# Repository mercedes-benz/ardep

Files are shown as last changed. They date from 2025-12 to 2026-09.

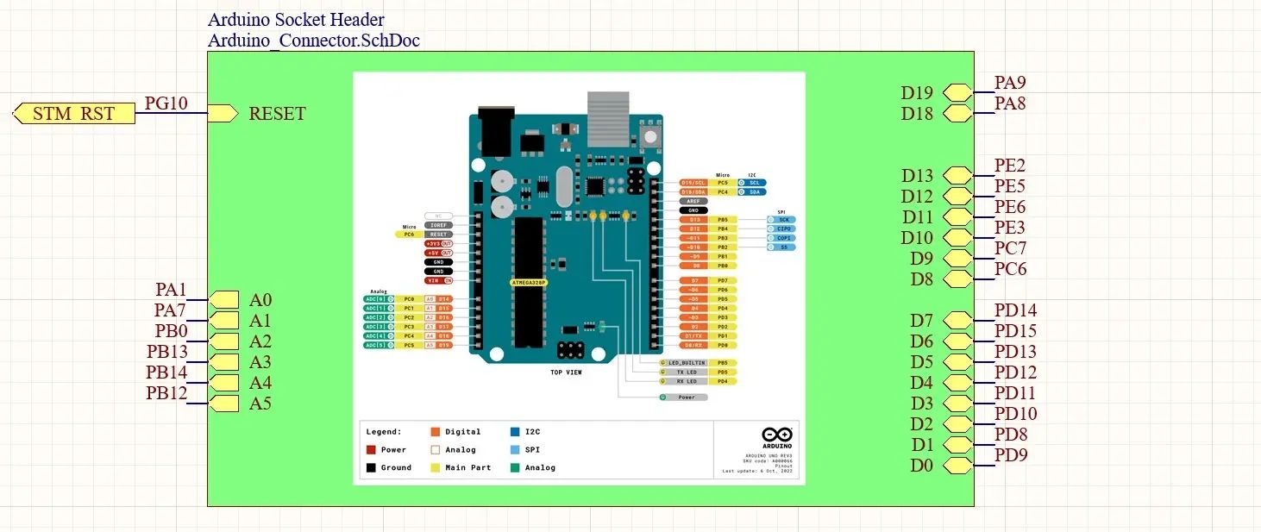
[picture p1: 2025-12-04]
_images/arduino_pinout_rev0_1.jpg

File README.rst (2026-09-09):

ARDEP - Automotive Rapid Development Platform
#############################################



ARDEP (**A**\ utomotive **R**\ apid **DE**\ velopment **P**\ latform) is an open-source hardware and software platform 
that simplifies automotive development. It combines a feature-rich development board with a robust 
Zephyr-based software framework, enabling you to build and deploy automotive applications quickly.

Whether you're prototyping a new automotive device or experimenting with diagnostics,
ARDEP provides the tools and infrastructure you need.

Waypoints
=========

* **Documentation**
   * `Documentation <https://mercedes-benz.github.io/ardep/>`_
   * `Getting Started Guide <https://mercedes-benz.github.io/ardep/getting_started/index.html>`_

* **Hardware**
   * `Hardware documentation <https://mercedes-benz.github.io/ardep/boards/mercedes/ardep/doc/index.html>`_
   * `PowerIO Shield documentation <https://mercedes-benz.github.io/ardep/boards/shields/power_io_shield/doc/index.html>`_
   * `Hardware files <hardware/>`_
   * `Get the hardware (Crowd Supply) <https://www.crowdsupply.com/frickly-systems/ardep>`_

* **Software**
   * `UDS Library documentation <https://mercedes-benz.github.io/ardep/lib/uds/README.html>`_
   * `Sample documentation <https://mercedes-benz.github.io/ardep/samples/>`_
   * `Sample sources <samples/>`_

* **Project**
   * `Contributing guidelines <CONTRIBUTING.md>`_
   * `License <LICENSE>`_

At a Glance
===========

* **Complete hardware solution** - Ready-to-use development board with CAN, LIN and other common communication interfaces
* **PowerIO Shield** - Extended Power capabilities for 6 Outputs and 6 Inputs up to 48V and 3A per channel
* **Automotive-ready software** - Built-in UDS diagnostics (ISO 14229) and DFU firmware update support
* **Proven foundation** - Based on the reliable Zephyr RTOS with a large ecosystem
* **Fast prototyping** - Develop and iterate quickly without worrying about hardware integration

Key Features
============

**Hardware**

* **Integrated development board** - Open-source design with everything you need built-in
* **Automotive communication** - Onboard CAN and LIN transceivers (no external components needed)
* **Debugger & programmer onboard** - Integrated debugger and programmer with UART connection
* **PowerIO Shield** - Extended power capabilities with six 3A high-side switches at up to 48V
* **Arduino headers** - Compatible with a wide range of Arduino shields and accessories

**Software & Framework**

* **Zephyr RTOS based** - Built on the reliable, widely-adopted open-source Zephyr RTOS
* **Automotive diagnostics** - Built-in UDS support (ISO 14229) for professional diagnostics
* **Firmware updates** - Integrated DFU (Device Firmware Update) over UDS
* **Modular architecture** - Clean separation of concerns, designed for long-term maintainability
* **Rich connectivity** - CAN, LIN, SPI, I2C, UART and more with unified and easy-to-use APIs

Hardware availability
===============

Frickly Systems has started a Crowd Supply campaign to make the hardware available for purchase. Subscribe to notified when it launches at:



Getting Started
===============

Ready to dive in? Start with the `Getting Started Guide <https://mercedes-benz.github.io/ardep/getting_started/index.html>`_ 
for a comprehensive step-by-step introduction. You'll find sample projects and examples to help you get up and running quickly.

For detailed information on using ARDEP, API references, and troubleshooting, refer to the 
`complete documentation <https://mercedes-benz.github.io/ardep/>`_.

Contributing
============

Contributions are welcome and appreciated.
Please see `CONTRIBUTING.md <CONTRIBUTING.md>`_ for guidelines and further
information.

License
=======

Copyright Mercedes-Benz AG

This project is licensed under the `Apache 2.0 License <LICENSE>`_.

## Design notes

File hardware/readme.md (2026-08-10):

# Hardware Source files
This directory includes all hardware source files for the ARDEP Mainboard and auxilary shields.

## KiCad Conversion
The initial project development was started in Altium designer. After the Hardware release of the ARDEP Mainboard rev 2.1 and the Power IO shield rev 1.0 in December 2025, the Altium source files were converted to KiCad.

From this point on, the KiCad source files are considered as the active project documents while the Altium source files are treated as legacy data and will no longer be actively maintained.

## OpenSCAD file
OpenSCAD enclosure models are stored in this hardware folder as source .scad files.
Use descriptive names such as ardep_enclosure.scad and prefer parametric dimensions/cutouts.
For each new model, include a short note with parameters and recommended print settings.
Generated STL files should only be committed when explicitly requested by maintainers.

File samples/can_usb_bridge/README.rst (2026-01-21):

.. _can_usb_bridge_sample:

CAN USB Bridge sample
#####################

This sample uses the application from the CANnectivity repository and just provides overlays for compatability with the ARDEP board.

It creates a CAN to USB bridge connecting *CAN A* of the ARDEP board to the USB Host.

The `CANnectivity repository <https://github.com/CANnectivity/cannectivity>`_ is automatically downloaded as a Zephyr module with ``west update`` on workspace setup. You can find it under ``{WORKSPACE_ROOT}/modules/lib/cannectivity``.

As a *one-time setup*, you need to install the CANnectivity UDEV rule (analogous to the one we installed in :ref:`getting_started` guide):

.. code-block::

    sudo cp {WORKSPACE_ROOT}/modules/lib/cannectivity/99-cannectivity.rules /etc/udev/rules.d/
    sudo udevadm control --reload-rules
    sudo udevadm trigger

.. note::

    Since the app manages the usb stack, there will be no USB-CDC-ACM device present to see the logs.
    Instead, they are redirected to UART-A (The same UART the bootloader uses).

Flash and run the example
-------------------------

Build the example with:

.. tabs::

    .. tab:: Ardep v2.0.0 and later
        .. code-block::

            west build --board ardep@2.0.0 ../modules/lib/cannectivity/app -- \
                -DFILE_SUFFIX=usbd_next \
                -DEXTRA_CONF_FILE=../../../../ardep/samples/can_usb_bridge/cannectivity.conf \
                -DEXTRA_DTC_OVERLAY_FILE=../../../../ardep/samples/can_usb_bridge/cannectivity_2_0_0.overlay

    .. tab:: Ardep v1.0.0

        .. code-block::

            west build --board ardep@1.0.0 ../modules/lib/cannectivity/app -- \
                -DFILE_SUFFIX=usbd_next \
                -DEXTRA_CONF_FILE=../../../../ardep/samples/can_usb_bridge/cannectivity.conf \
                -DEXTRA_DTC_OVERLAY_FILE=../../../../ardep/samples/can_usb_bridge/cannectivity_1_0_0.overlay
                
The ``FILE_SUFFIX`` selects the `prj_usbd_next.conf` file from the CANnectivity app folder, which enables the new USB stack.

The ``EXTRA_CONF_FILE`` and ``EXTRA_DTC_OVERLAY_FILE`` options specify the additional configuration and overlay files found in the samples directory.
The path is relative to the application directory.

Flash the app using dfu-util:

.. code-block:: bash

    west flash

After flashing, you should see an USB device named "Generic CANnectivity USB to CAN adapter" with a VID/PID of ``1209:ca01``.
Additionally you should also see a new can device on your host system.
Configure it as follows to enable it:

.. code-block:: bash
   
    # Replace can0 with the device name on your system

    sudo ip link set can0 type can bitrate 500000
    sudo ip link set up can0

.. warning::
   
    For users of the *ARDEPv1* board:

    Since we don't use the default USB PID/VID of the ARDEP board, the default ARDEP DFU will not work for firmware updates.
    Put the device in bootloader mode to flash another firmware.

    See :ref:`bootloader_mode` for more information.

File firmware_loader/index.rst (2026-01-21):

.. _firmware_loader:

Firmware Loader
###############

This firmware loader is used to update **application** firmware on ARDEP devices. It supports both **UDS DFU** (Unified Diagnostic Services over CAN) and **USB DFU** (Device Firmware Update via USB), providing flexible firmware update mechanisms for all ARDEP board versions.

The bootloader runs this firmware under certain conditions, such as when the *BOOT* labeled jumper is set during start up,
when ``uds_switch_to_firmware_loader_with_programming_session()`` is called (or automatically with the UDS default instance), or when no valid application is flashed.

The firmware loader uses the UDS library's default instance for simplified UDS server setup, automatically handling CAN configuration and session management. It also provides USB DFU functionality for USB-based firmware updates.

.. important::

    Only applications can be updated via the firmware loader. Not the bootloader or the firmware loader itself.

For this firmware loader to work as intended, use sysbuild to build the bootloader with this firmware loader.

.. note::
    **Default for all boards**: This unified firmware loader is now the default boot logic for all ARDEP board versions (v1 and v2), eliminating the previous distinction between boards. Both UDS DFU and USB DFU are supported on all boards for application updates.
    
    **Upgrading from older ARDEP versions**: If you're using an older ARDEP repository version that differentiated between board versions, you must upgrade your bootloader via sysbuild using a debugger (OBD or external probe) to install the unified firmware loader.

Usage
+++++

The firmware loader supports two update mechanisms:

**UDS DFU (CAN-based updates):**

This firmware registers an *erase slot0* routine with id ``0xFF00`` which, if started via UDS, erases slot0 (the application slot).

Then, using `RequestDownload`, `TransferData`, `RequestTransferExit` the application can be updated. Finally, use an `ECUReset` to let mcuboot boot into the fresh application.

**USB DFU (USB-based updates):**

When the firmware loader is active and the device is connected via USB, it can accept firmware updates using the standard ``dfu-util`` tool.

- **v1 boards**: The default ``west flash`` runner uses dfu-util, so simply set the BOOT jumper, reset the board, and run ``west flash``
- **v2 boards**: To use USB DFU instead of the OBD run ``west flash --runner ardep``. Note that is usually better to use the on-board debugger (OBD) for flashing v2 boards.

Flashing firmware
+++++++++++++++++

If your application supports UDS firmware loading, you can use the :ref:`ardep_uds` runner to flash the new firmware.

Building using sysbuild
+++++++++++++++++++++++

See :ref:`uds_bootloader` on building an application together with this firmware loader.

The firmware loader is automatically included when building with sysbuild and provides both UDS and USB DFU support by default.

A good starting point in using this loader is using the :ref:`uds-sample`.

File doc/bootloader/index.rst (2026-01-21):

.. _bootloader:
   
Bootloader
##########

.. contents::
   :local:
   :depth: 2

Overview
++++++++

The ARDEP bootloader uses MCUBoot and a :ref:`firmware_loader` for firmware updates. This enables application upgrades either via UDS over CAN or USB DFU.

.. tabs::

    .. tab:: Ardep v2.0.0 and later

        The recommended upgrade mechanism is the on-board debugger using the `west flash` command or if needed using UDS over CAN.

    .. tab:: Ardep v1.0.0

        The recommended upgrade mechanism is USB DFU using the `west flash` command or if needed using UDS over CAN.

Building the bootloader
+++++++++++++++++++++++

The bootloader can be built using sysbuild together with a sample for flashing. To reset the board to a delivery state, use 

.. code-block:: bash

    west build -b ardep samples/led -p --sysbuild

to build the :ref:`led_sample` and bootloader

If you want to build for a specific board version, change the `-b` argument accordingly:

.. code-block:: bash

    west build -b ardep@1.0.0 samples/led -p --sysbuild

.. _flashing_the_bootloader:

Flashing the bootloader
+++++++++++++++++++++++

.. important::

    **Bootloader and firmware loader can ONLY be flashed via debugger:**
    
    - **v2.0.0 and later**: Must use the on-board debugger (OBD) - this is the **recommended and default** method
    - **v1.0.0**: Must use an external debug probe (e.g. J-Link, ST-Link)
    
    The firmware loader itself **cannot** be flashed via USB DFU or UDS DFU. Only **application** updates can use the firmware loader's DFU capabilities.

.. tabs::

    .. tab:: Ardep v2.0.0 and later

        The bootloader and firmware loader are flashed via the on-board debugger using the `west flash` command.

        Just run:

        .. code-block:: bash

            west flash

        This will flash the bootloader and firmware loader to the board.

    .. tab:: Ardep v1.0.0

        The bootloader and firmware loader are flashed with an external debug probe (e.g. J-Link) using the `west flash` command.

        For this connect the SWD Pins of the ARDEP board to the debug probe an run:

        .. code-block:: bash
           
            west flash -r {runner}

        The Pinout of the SWD connector is printed on the boards backside.

        See the `board.cmake` file under `boards/mercedes/ardep` for more info about supported debuggers/runners.

.. _bootloader_mode:

Firmware Loader Mode
++++++++++++++++++++

The firmware loader supports both **USB DFU** and **UDS DFU** update mechanisms for **application** updates. When you set the BOOT jumper, the bootloader enters the firmware loader, which provides both update methods.

.. important::

    The firmware loader can only update **applications**, not the bootloader or firmware loader itself. To update the bootloader or firmware loader, you must use the on-board debugger (v2) or external probe (v1).

It is helpful to see the Bootloader console output on ``UART-A`` for this.

Entering Firmware Loader Mode
==============================

To enter the firmware loader mode, pull the ``PE4`` pin (labeled *BOOT*) to a LOW state (by setting the jumper) while power-cycling or pushing the Reset button.

The firmware loader will be active and ready to accept **application** firmware updates via either USB DFU or UDS (CAN).

On ``UART-A`` you will see output indicating the bootloader has started the firmware loader.

.. note::

    ``UART-A`` is the output that is forwarded by the on-board debugger (on v2 boards) or available via the UART-A pins.

Upgrading the Application Firmware
===================================

You can upgrade **application** firmware using either method:

**Via On-board Debugger (v2)**

- Note that this method only works on ARDEP v2.0.0 and later boards with an on-board debugger.
- Build the application firmware you want to flash (assuming it is in the *build* directory)
- Set the BOOT jumper and reset the board
- Perform the upgrade with ``west flash``
- Wait for the upgrade to complete

**Via USB DFU:**

- Note that this method works on all ARDEP boards (v1 and v2), but the first option is generally better for v2+ boards
- Build the application firmware you want to flash (assuming it is in the *build* directory)
- Set the BOOT jumper and reset the board
- Perform the upgrade with ``west flash`` (for v2+ boards, set the runner: ``west flash --runner ardep``)
- Wait for the upgrade to complete

**Via UDS (CAN):**

- Use the UDS diagnostic services over CAN to request a programming session
- The firmware loader will handle the application update process
- See :ref:`firmware_loader` for details

.. _uds_bootloader:

UDS and USB DFU Support via Firmware Loader
++++++++++++++++++++++++++++++++++++++++++++

.. note::

    **All ARDEP boards** (v1 and v2): The unified firmware loader is now the **default** boot logic for all board versions. You can build any application with sysbuild and it will automatically include the firmware loader with support for both UDS DFU and USB DFU.
    
    **Upgrading from older ARDEP versions**: If your bootloader was built with an older ARDEP repository version that differentiated between board versions, you need to upgrade the bootloader using sysbuild (via OBD on v2 or external probe on v1) to get the unified firmware loader support.

For applications that require firmware updates over UDS (Unified Diagnostic Services) or USB DFU,
a :ref:`firmware_loader` is provided which can be built using sysbuild.

It is not recommended to build the firmware loader independently as the bootloader needs configuration options to handle the firmware loader correctly.

For demonstration purposes, build the :ref:`uds-sample` using sysbuild (which contains a ``sysbuild.conf``), which automatically builds the firmware loader:

.. code-block:: bash

    west build -b ardep samples/uds -p --sysbuild

If you wish to build your own application using the firmware loader, it is included by default when using sysbuild.

.. note::
    **Flashing considerations:**
    
    - **Bootloader and firmware loader**: Can ONLY be flashed via on-board debugger (v2) or external probe (v1)
    - **Applications**: Can be flashed via debugger OR via the firmware loader (USB DFU/UDS DFU)
    
    See :ref:`flashing_the_bootloader` for detailed instructions.

.. important::
    When using the default UDS instance (``CONFIG_UDS_DEFAULT_INSTANCE=y``, enabled by default on ARDEP boards), the firmware loader switch is handled automatically on programming session requests unless disabled with ``CONFIG_UDS_DEFAULT_INSTANCE_DISABLE_SWITCH_TO_FIRMWARE_LOADER=y``.
    
    If you create a custom UDS instance or disable the automatic switch, you must call ``uds_switch_to_firmware_loader_with_programming_session()`` in your diagnostic session control action handler when a programming session is requested.

To flash an application with the UDS firmware loader, see :ref:`ardep_uds`.

Sysbuild
++++++++

With sysbuild, multiple applications (i.e. bootloader, main application and firmware loader) are built together using just one build command.

More information is available in the official `Zephyr Sysbuild documentation <https://docs.zephyrproject.org/4.2.0/build/sysbuild/index.html>`_.

Sysbuild basics
===============

There are multiple things that differ from a normal west build:

First, there are multiple targets for using menuconfig, one for each "domain":

.. code-block:: bash

    # Main application menuconfig
    west build -t menuconfig

    # Bootloader menuconfig
    west build -t mcuboot_menuconfig

    # Firmware loader menuconfig
    west build -t firmware_loader_menuconfig

    # Sysbuild menuconfig
    west build -t sysbuild_menuconfig

Second, you can switch between domains when debugging by specifying the domain:

.. code-block:: bash

    # Debug main application
    west debug

    # Debug bootloader
    west debug --domain mcuboot

    # Debug firmware loader
    west debug --domain firmware_loader

Finally, when flashing, you can either specify no domain, which flashes all domains in series or you can specify a domain to flash only that domain:

.. code-block:: bash

    # Flash all domains (bootloader, firmware loader and main application)
    west flash

    # Flash only bootloader
    west flash --domain mcuboot

    # Flash only firmware loader
    west flash --domain firmware_loader

    # Flash only main application (when building sample/uds the sample-name would be uds)
    west flash --domain <sample-name>

.. important::
    Note that on ARDEP v1 boards, only the main application can be flashed using the ardep runner. This also means that the bootloader and firmware loader must be flashed using an external debug probe, see :ref:`flashing_the_bootloader`.

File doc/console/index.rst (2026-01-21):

.. _console:

Console Output
##############

.. contents::
   :local:
   :depth: 2

Firmware Output
===============

The application output is sent on ``UART-A``.

.. tabs::

    .. tab:: Ardep v2.0.0 and later

        The output of the application is additionally forwarded via the on-board debugger to a USB cdc-acm device on the host system.

    .. tab:: Ardep v1.0.0

       By default, every application built for the *ardep* board will include a USB cdc-acm driver.
       This means, when connecting the board via USB to your PC, a new serial device should be visible in your system.

You can use the cdc-acm device to communicate with the board. The default baudrate is 115200.

.. tabs::

    .. tab:: Linux
    
        The serial device is usually displayed as */dev/ttyACMx*, */dev/ttyUSBx* or similar.

        Use a serial terminal emulator (e.g. *screen*, *minicom*, *picocom*) to connect to the device.
        
        .. code-block:: bash

            screen /dev/ttyACM0 115200

    .. tab:: Windows

        The serial device is usually displayed in your *Windows Device Manager* under *Ports (COM & LPT)* e.g. as *COM5*.

        Use *putty* or a similar terminal emulator to connect to the device.

        Connect to the COM port by selecting *Serial* in the *Connection type* section and entering the COM port number (e.g. *COM5*) in the *Serial line* field, setting the speed to 115200.

Bootloader and Firmware Loader Output
======================================

The bootloader and firmware loader output is available on the ``UART-A`` interface.

.. tabs::

    .. tab:: Ardep v2.0.0 and later

       Just as the firmware's output, the bootloader and firmware loader output is also forwarded via the on-board debugger to a cdc-acm device on the host system.

    .. tab:: Ardep v1.0.0

       The bootloader and firmware loader do not contain the cdc-acm driver and only emit output via ``UART-A``.
       If you want to see the bootloader or firmware loader output on your PC, you will need an external UART to USB adapter connected to the ``UART-A`` pins.

.. note::
    
    The unified firmware loader is now used by default on all board versions, supporting both UDS DFU and USB DFU update mechanisms.

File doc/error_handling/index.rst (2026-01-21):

.. _error_handling:

Error Handling
##############

.. contents::
   :local:
   :depth: 2

.. note::

    The following instructions only apply to Ardep v1 since later versions have an :ref:`on_board_debugger` and the bootloader logs are accessible via the forwarded UART-A device.
    Additionally, you can flash the bootloader and the firmware via ``west flash`` using the on-board debugger.
    
    **All ARDEP boards** now use the unified firmware loader by default, which supports both USB DFU and UDS DFU for firmware updates.

When encountering an error, you have several options, depending on the severity of the error.
Generally, it is helpful to see if your application gets started from the bootloader.
See the :ref:`console` documentation for more information about where you find the application and bootloader output.

If your application keeps running, you can just perform an update via the firmware loader. See the :ref:`getting_started` guide for an example.
The unified firmware loader supports both USB DFU and UDS DFU update mechanisms.
    
If your application keeps hanging itself up (e.g. segfaults) and a firmware loader update is not possible, boot into the :ref:`bootloader_mode` and flash a new application from there.

If you can't get into bootloader mode, you should delete the whole flash memory and flash a new bootloader and application.
For this, you need to connect an external debugger on the SWD pins on the board (or use the on-board debugger on v2 boards).

To build the bootloader with the unified firmware loader, you can use sysbuild:

    ``west build -b ardep samples/led -p --sysbuild``
    
Then erase the flash memory of the ardep board.

Next, flash the bootloader. You can use a debugger of your choice or use the ``west flash`` command.
For an overview of the ``west flash`` command see `Zephyr's documentation on the west command <https://docs.zephyrproject.org/4.2.0/develop/west/build-flash-debug.html#flashing-west-flash>`_, ``west flash -h`` and the *board.cmake* file under *boards/mercedes/ardep* for an overview of supported runners.

**Important**: The bootloader and firmware loader can ONLY be flashed via on-board debugger (v2) or external debug probe (v1).

After flashing the bootloader, flash the application of your choice. See the :ref:`getting_started` guide and the :ref:`bootloader_mode` documentation for this.

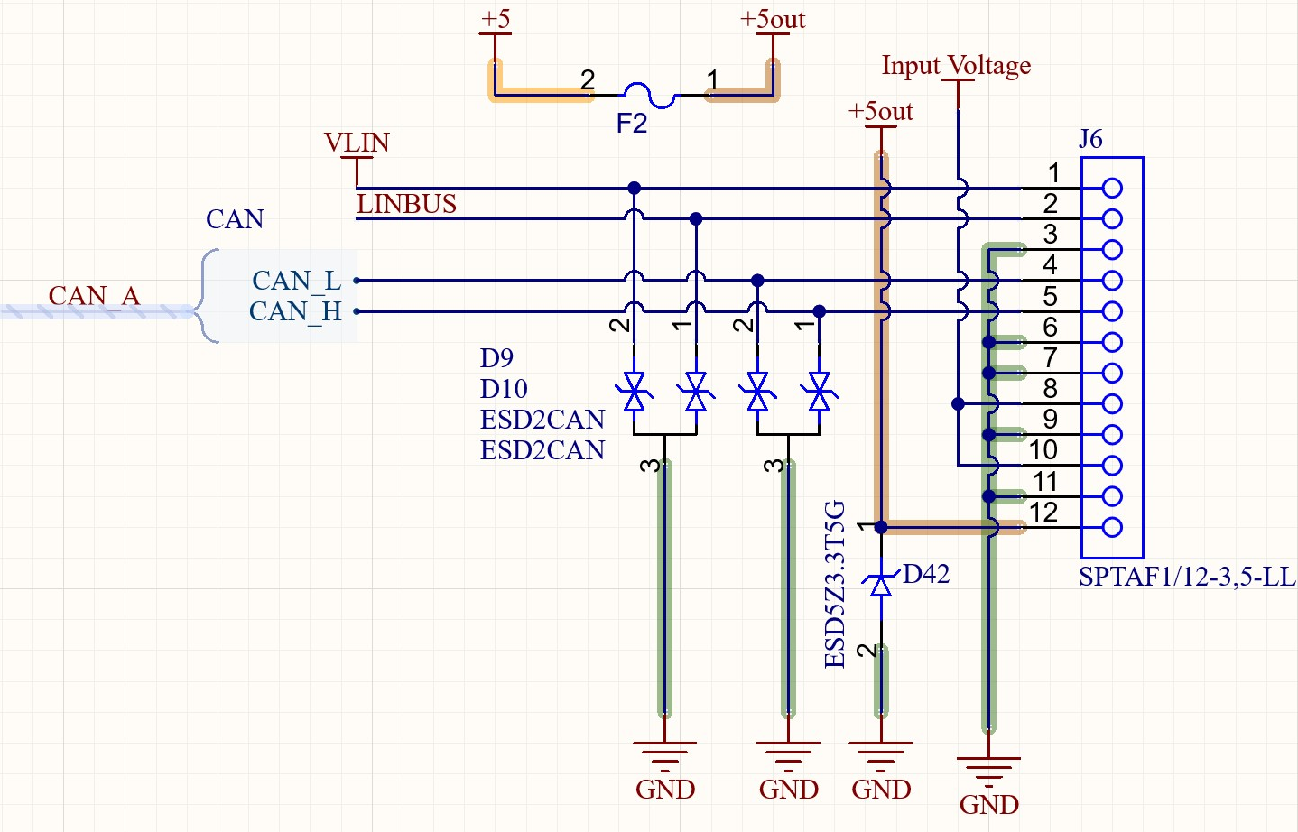
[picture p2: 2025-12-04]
_images/can_and_lin_spring_terminal_pinout.png

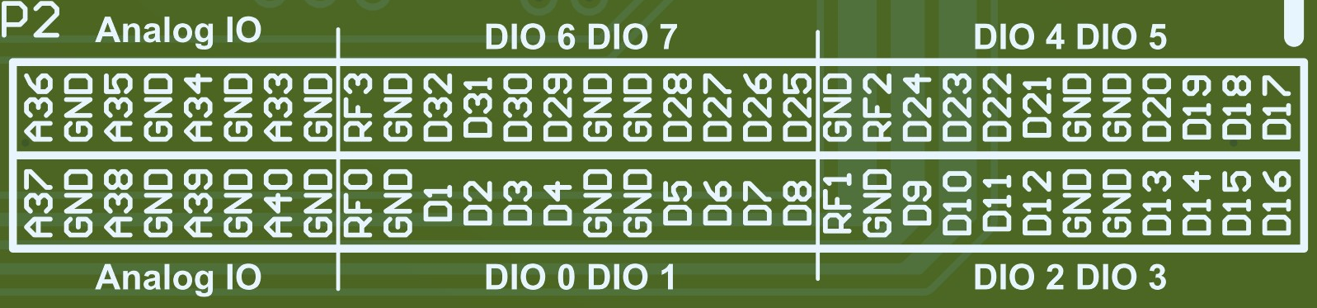
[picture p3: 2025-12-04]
_images/hv_shield_io_banks_pinout.png

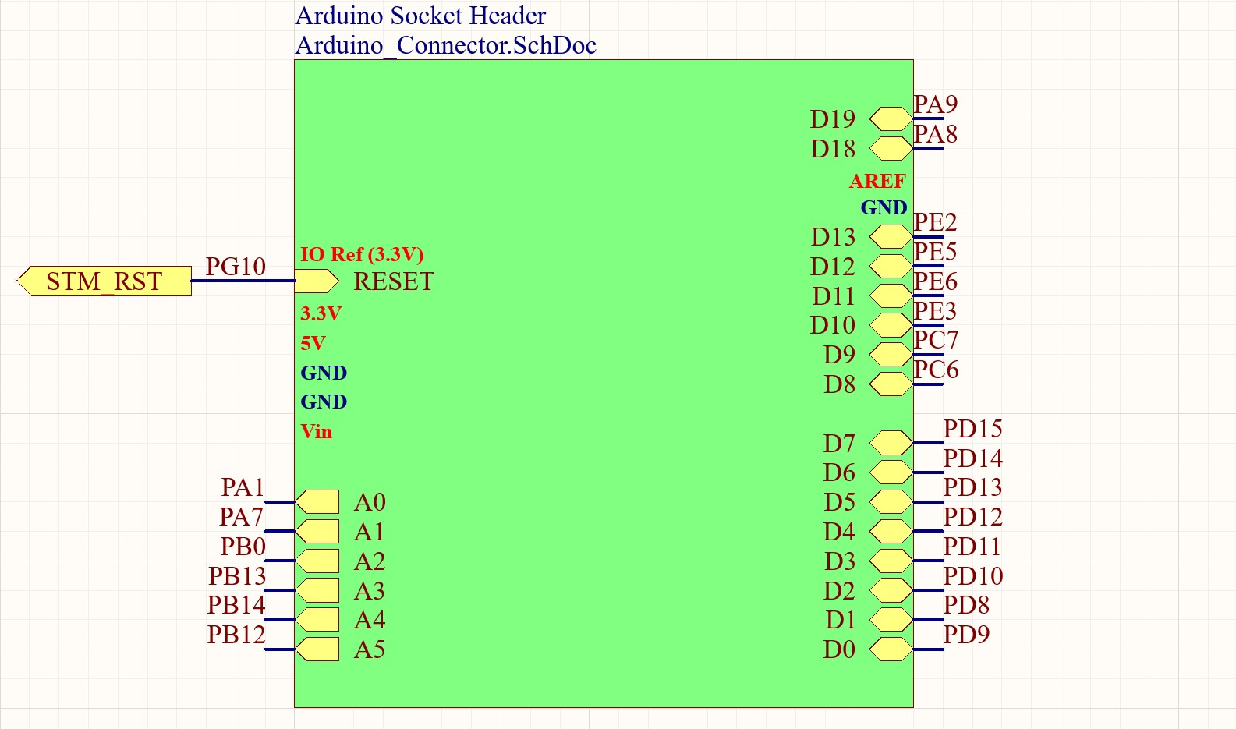
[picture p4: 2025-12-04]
_images/arduino_pinout_rev0_2.png

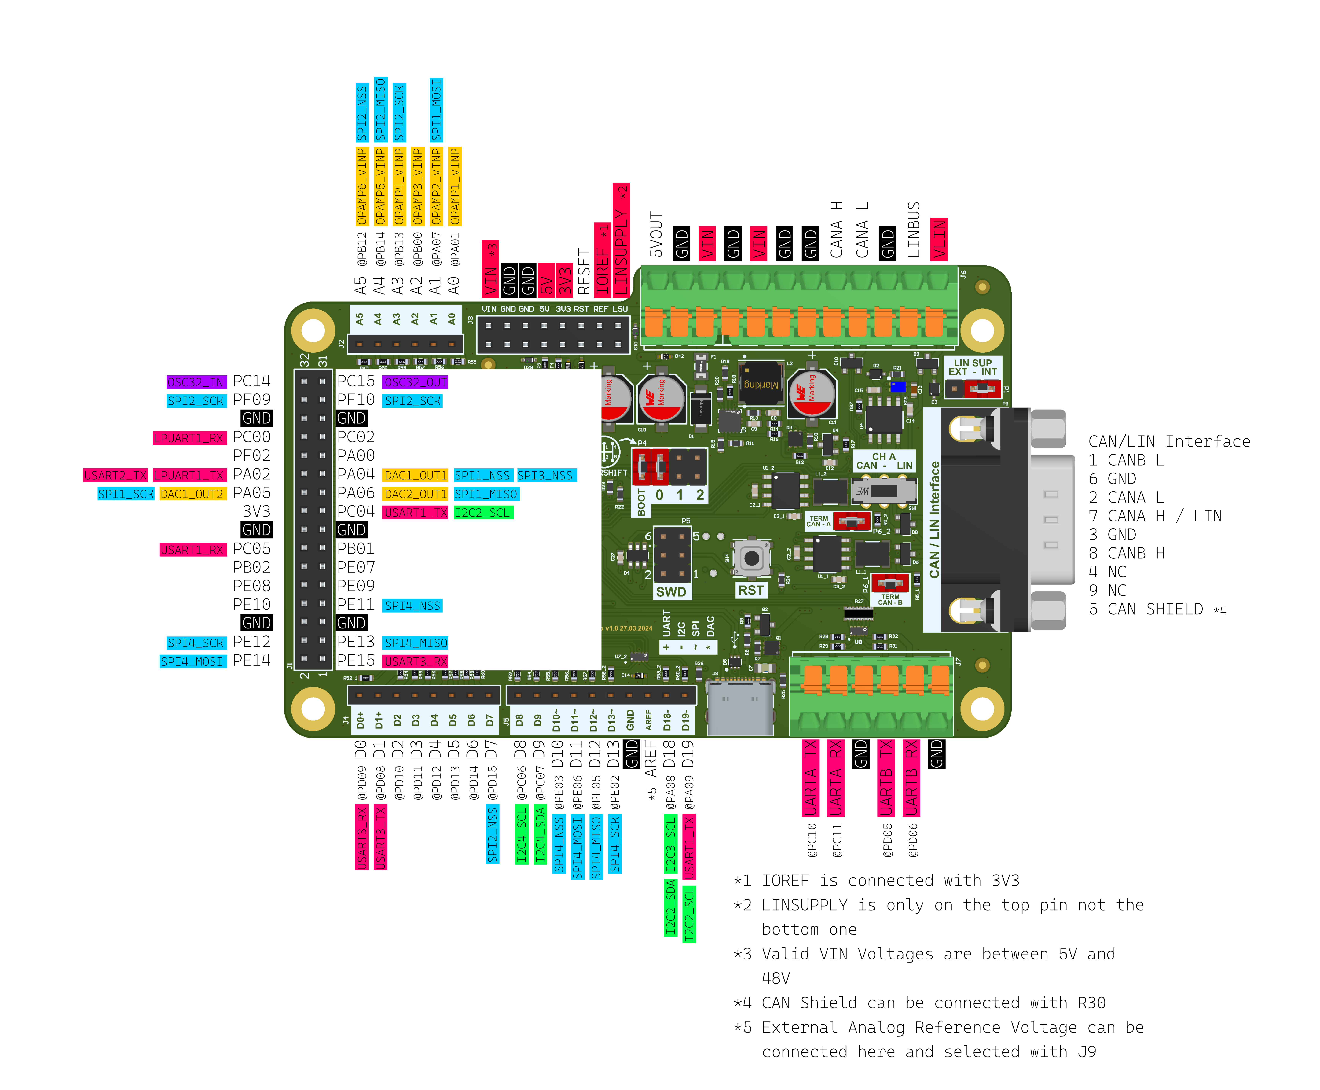
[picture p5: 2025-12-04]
_images/pinout.png

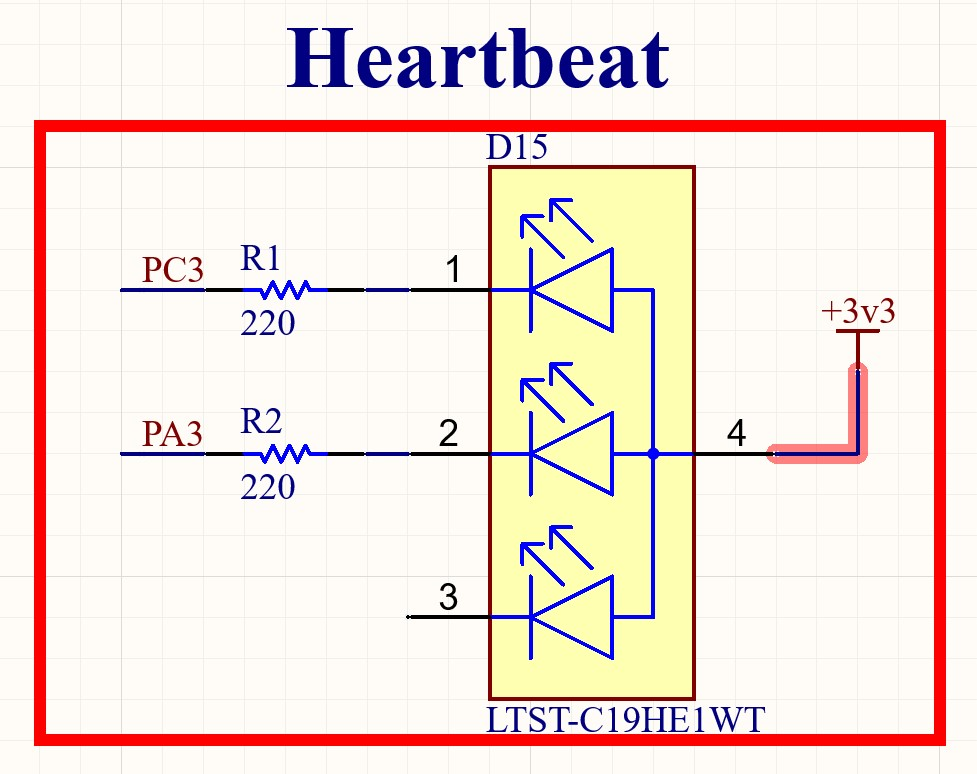
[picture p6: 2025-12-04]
_images/heartbeat_led_schematic.png

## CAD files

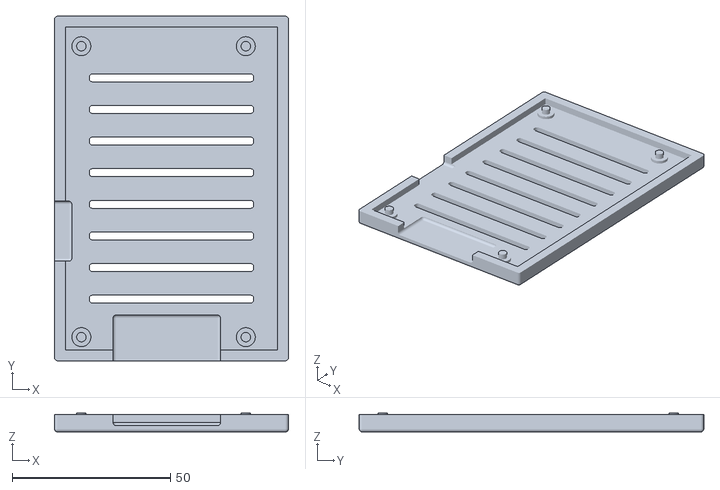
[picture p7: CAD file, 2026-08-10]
hardware/openSCAD_model/ardep_enclosure.stl
74.0 x 109.0 x 6.00

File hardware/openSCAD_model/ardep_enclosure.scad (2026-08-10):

$fn = 100;
// -----------------------
// User Parameters
// -----------------------
show_supports = true;
show_vents = true;
show_vga_cutout = true;
show_power_cutout = true;

outer_size = [72, 107, 8];
inner_size = [67, 102, 10];
outer_round_r = 1;

vga_pos = [-1.5, -51, 3];
vga_size = [32, 20, 10];

power_pos = [-40, -13.5, 3];
power_size = [15, 17, 10];

vent_x_range = [-35, 35];
vent_step = 10;
vent_size = [50, 0.5, 10];

support_points = [
    [-28.5, -47],
    [-28.5,  45],
    [ 23.5,  45],
    [ 23.5, -47]
];

// -----------------------
// Helper Modules
// -----------------------
module rounded_box(size_xyz, r) {
    minkowski() {
        cube(size_xyz, center = true);
        sphere(r);
    }
}
module support_post(xy, base_h = 2, base_r = 3, pin_h = 4, pin_r = 1.5) {
    translate([xy[0], xy[1], -2]) cylinder(h = base_h, r = base_r, center = true);
    translate([xy[0], xy[1], -1]) cylinder(h = pin_h, r = pin_r, center = true);
}

module cutout_rounded(size_xyz, pos_xyz, r) {
    translate(pos_xyz) rounded_box(size_xyz, r);
}

module vents() {
    for (x = [vent_x_range[0] : vent_step : vent_x_range[1]]) {
        translate([0, x, 0]) rounded_box(vent_size, outer_round_r);
    }
}

module case_body() {
    difference() {
        rounded_box(outer_size, outer_round_r);
        translate([0, 0, 3]) cube(inner_size, center = true);
        translate([0, 0, 3]) cube([100, 150, 5], center = true);

        if (show_vga_cutout) cutout_rounded(vga_size, vga_pos, outer_round_r);
        if (show_power_cutout) cutout_rounded(power_size, power_pos, outer_round_r);
        if (show_vents) vents();
    }
}

// -----------------------
// Final Model
// -----------------------
case_body();

if (show_supports) {
    for (pt = support_points) {
        support_post(pt);
    }
}

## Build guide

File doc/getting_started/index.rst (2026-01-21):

.. _getting_started:

Getting Started
################

.. contents::
   :local:
   :depth: 2

Follow this guide to:

- Set up your first workspace
- Install the `Zephyr RTOS <https://zephyrproject.org/>`_ SDK
- Enable the dfu-util to perform Firmware upgrades
- Build and flash your first sample application

The instructions here closely follow the `Zephyr RTOS Getting Started Guide <https://docs.zephyrproject.org/4.2.0/develop/getting_started/index.html>`_ but are modified to setup an ARDEP workspace instead of a vanilla Zephyr workspace. [1]_

Install dependencies
*********************

Follow Zephyr's  `OS Update Section <https://docs.zephyrproject.org/4.2.0/develop/getting_started/index.html#select-and-update-os>`_ and then the `Install dependencies <https://docs.zephyrproject.org/4.2.0/develop/getting_started/index.html#install-dependencies>`_ section.

    .. note::

        **For Windows user:**
        
        - You might need to manually add the *7zip* installation folder to your *$PATH*. It is usually installed under ``C:\Program Files\7-Zip``. [2]_

        - One of your testers reported, that the ``python`` executable was actually called ``py`` on his device. You can check this with the ``python --version`` or ``py --version`` in a command prompt. If you see the version (e.g. `Python 3.13.7`) the executable is found.

Install the additional dependencies for the ardep board:

.. tabs::
   
   .. tab:: Linux

    .. code-block:: bash

        sudo apt update
        sudo apt install --no-install-recommends iproute2 dfu-util git-lfs gdb-multiarch

   .. tab:: Windows
   
        - Install the latest `dfu-util <https://dfu-util.sourceforge.net/>`_ from the `release page <https://dfu-util.sourceforge.net/releases/>`_ (e.g. *dfu-util-X.YY-binaries.tar.xz*), extract the archive and ensure the executables are in your *$PATH*. [2]_

          Open a new *command prompt* or *powershell* and run ``dfu-util --version`` to check that the command is available.
          
        - Install the latest `ARM toolchain <https://developer.arm.com/downloads/-/arm-gnu-toolchain-downloads>`_ for a current version of GDB. On the download page, select the latest *AArch32 bare-metal target (arm-none-eabi)* toolchain (e.g. *arm-gnu-toolchain-14.3.rel1-mingw-w64-x86_64-arm-none-eabi.exe*) and install it.

          It is recommended, that you add the *bin* directory of the installation to your *$PATH* for easier access to the executables (e.g. the path ``C:\Program Files (x86)\Arm GNU Toolchain arm-none-eabi\14.3 rel1\bin``). [2]_

Set up your workspace
*********************

We will clone the `ARDEP repository <https://github.com/mercedes-benz/ardep>`_, `Zephyr <https://github.com/zephyrproject-rtos/zephyr>`_ and all required `modules <https://docs.zephyrproject.org/4.2.0/develop/modules.html#modules>`_ into a new `west <https://docs.zephyrproject.org/4.2.0/develop/west/index.html#west>`_ workspace and install all required python dependencies in a `Python virtual environment <https://docs.python.org/3/library/venv.html>`_.

In the following, we use `ardep-workspace` as the name for the workspace and locate it in our *$HOME* directory, but you can choose any name and location you want.

   .. tabs::

        .. tab:: Linux
        
            #. Create a new virtual environment

                .. code-block:: bash

                    python3 -m venv ~/ardep-workspace/.venv

            #. Activate the virtual environment

                .. code-block:: bash

                    source ardep-workspace/.venv/bin/activate
                    
                .. note::    

                    Remember to do activate the virtual environment whenver you start working.
                
            #. Install west:

                .. code-block:: bash

                    pip install west
                    
            #. Get the ARDEP source code:

                .. code-block:: bash
                    
                    west init -m https://github.com/mercedes-benz/ardep.git ~/ardep-workspace 
                    
            #. Get the source code for Zephyr and all its dependencies:

                .. code-block:: bash
                    
                    cd ~/ardep-workspace
                    west update

            #. Export a `Zephyr CMake package <https://docs.zephyrproject.org/4.2.0/build/zephyr_cmake_package.html#cmake-pkg>`_. This allows CMake to automatically load boilerplate code required for building Zephyr applications.

                .. code-block:: bash
                
                    west zephyr-export

            #. Install python dependencies for other *west* commands:

                .. code-block:: bash
                
                    west packages pip # Lists all requirement.txt files that get installed
                    west packages pip --install # Actually install the packages

        .. tab:: Windows
        
            #. Open a command prompt or PowerShell as a **regular user**
            #. Create a new virtual environment
                           
                .. tabs::
                
                    .. tab:: Batchfile

                        .. code-block:: batch

                            cd %HOMEPATH%
                            python -m venv ardep-workspace\.venv   

                    .. tab:: PowerShell
                    
                        .. code-block:: powershell
                        
                            cd $Env:HOMEPATH
                            python -m venv ardep-workspace\.venv

            #. Activate the virtual environment

                .. tabs::
                
                    .. tab:: Batchfile

                        .. code-block:: batch

                            ardep-workspace\.venv\Scripts\activate.bat

                    .. tab:: PowerShell
                    
                        .. code-block:: powershell

                            ardep-workspace\.venv\Scripts\Activate.ps1                        

                .. note::    

                    Remember to do activate the virtual environment whenver you start working.
                
            #. Install west:

                .. code-block:: bash

                    pip install west
                    
            #. Get the ARDEP source code:

                .. code-block:: bash
                    
                    west init -m https://github.com/mercedes-benz/ardep.git ardep-workspace 
                    
            #. Get the source code for Zephyr and all its dependencies:

                .. code-block:: bash
                    
                    cd ardep-workspace
                    west update

            #. Export a `Zephyr CMake package <https://docs.zephyrproject.org/4.2.0/build/zephyr_cmake_package.html#cmake-pkg>`_. This allows CMake to automatically load boilerplate code required for building Zephyr applications.

                .. code-block:: bash
                
                    west zephyr-export

            #. Install python dependencies for other *west* commands:

                .. code-block:: bash
                
                    west packages pip # Lists all requirement.txt files that get installed
                    west packages pip --install # Actually install the packages

Install the Zephyr SDK
****************************

We will install the `Zephyr SDK <https://docs.zephyrproject.org/4.2.0/develop/toolchains/zephyr_sdk.html#toolchain-zephyr-sdk>`_ which contains the toolchain for every by Zephyr supported architectures. Additionally it contains host tools for Linux such as a custom QEMU and OpenOCD build for emulation, flashing and debugging.

   .. tabs::

        .. tab:: Linux
        
            Install the Zephyr SDK using ``west sdk install``.

                .. code-block:: bash
                
                    cd ~/ardep-workspace/zephyr
                    west sdk install
                    
                .. note::

                    See ``west sdk install --help`` for more command options (e.g. install location)

        .. tab:: Windows
        
            Install the Zephyr SDK using ``west sdk install``.
                           
                .. tabs::
                
                    .. tab:: Batchfile

                        .. code-block:: batch

                            cd %HOMEPATH%\ardep-workspace\zephyr
                            west sdk install

                    .. tab:: PowerShell
                    
                        .. code-block:: powershell

                            cd $Env:HOMEPATH\ardep-workspace\zephyr
                            west sdk install
                           
                .. note::

                    See ``west sdk install --help`` for more command options (e.g. install location)

Enable the DFU-Util to perform firmware upgrades
************************************************

.. note::

    This step is only required if you have a board revision < 2.0.0

.. tabs::

    .. tab:: Linux

        .. code-block:: bash

            west ardep create-udev-rule
            sudo udevadm control --reload-rules
            sudo udevadm trigger
            
        This rule allows ``dfu-util`` to access your ardep board without sudo privileges (required for firmware upgrades via ``dfu-util``).
        
        If your ardep board is already connected, unplug and replug it.

    .. tab:: Windows
    
        We need to install WinUSB drivers for the device in order to be able to use dfu-util.

        You can use the `Zadig <https://zadig.akeo.ie/>`_ tool to install the drivers.
        
        If you haven't connected your *ARDEP* board to host, connect it now.

        After starting *Zadig*, ensure the *List all devices* option is turned on in the Options menu.
        Then, in the dropdown menu, select *Ardep (Interface 0)* install the *WinUSB* driver. Then repeat the step for *Ardep (Interface 2)*.
        This allows us to set the device into DFU mode.
        
        Installing WinUSB driver using Zadig
        
        We also need to install a driver for the DFU mode. For this, we need to build a sample application and unsuccessfully try to flash the firmware (see `Build your first app`_).
        
        After the initial flash command failed, select the *Ardep board* in the dropdown menu and install the *WinUSB* driver again.
        
        Now, flashing the app should succeed.

Enable the Black-Magic Debugger on your host
********************************************

.. note::

    This step is recommended, if you have a board revision >= 2.0.0

Perform the `Connecting to your Computer <https://black-magic.org/getting-started.html#connecting-to-your-computer>`_ Step in the *Getting Started Guide* of the Black-Magic Debugger.

This enables you to use the on-board debugger without root/admin privileges.

Build your first app 
********************

Build the :ref:`led_sample` with:

    .. tabs::

        .. tab:: Linux

            .. code-block:: bash

                cd ~/ardep-workspace/ardep
                west build --board ardep samples/led

        .. tab:: Windows
        
            .. tabs::

                .. tab:: Batchfile

                    .. code-block:: batch

                        cd %HOMEPATH%\ardep-workspace\ardep
                        west build --board ardep samples\led
                        
                .. tab:: PowerShell

                    .. code-block:: powershell

                        cd $Env:HOMEPATH\ardep-workspace\ardep
                        west build --board ardep samples\led
                        
.. note::

    **ARDEP boards are shipped with the bootloader and firmware loader pre-installed.** You can start building and flashing applications immediately. You only need to flash the bootloader and firmware loader if you're upgrading them or recovering from a corrupted state.
    
    All ARDEP boards now use the unified firmware loader by default, which supports both UDS DFU (via CAN) and USB DFU (via USB) for **application** updates. If you're using an older board version, append the board version to the board name (e.g. ``--board ardep@1.0.0`` or ``--board ardep@1`` for version 1).

.. important::

    Use the DEBUG USB Port on the ARDEP v2 board for flashing and debugging

Flash the app:

    .. code-block:: bash

        west flash
        
.. note::

    **Default flash runners:**
    
    - **v2 boards**: ``west flash`` uses the on-board debugger (OBD) by default
    - **v1 boards**: ``west flash`` uses the ardep runner (dfu-util) by default
    
    **For application updates:**
    
    - **v2**: Simply run ``west flash`` (uses the OBD)
    - **v1**: Run ``west flash`` OR use an external probe with ``west flash -r {runner}``
    
    **For bootloader/firmware loader updates (only when upgrading or recovering):**
    
    - **v2**: Use ``west flash`` with sysbuild (uses the OBD), see :ref:`flashing_the_bootloader`
    - **v1**: Must use an external debug probe: ``west flash -r {runner}`` with sysbuild
    
    **Important**: The bootloader and firmware loader themselves can ONLY be flashed via debugger (OBD or external probe), never via DFU.

.. [1] Tested on Ubuntu 24.04 and Windows (Version 24H2 Build 26100.5074), Zephyr SDK 0.17.2 and Zephyr RTOS 4.2.0

.. [2] See `here <https://www.computerhope.com/issues/ch000549.htm>`_ for a guide on how to add a folder to the *$PATH*

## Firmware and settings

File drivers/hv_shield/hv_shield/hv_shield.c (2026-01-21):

/*
 * SPDX-FileCopyrightText: Copyright (C) Frickly Systems GmbH
 * SPDX-FileCopyrightText: Copyright (C) MBition GmbH
 *
 * SPDX-License-Identifier: Apache-2.0
 */

#define DT_DRV_COMPAT hv_shield

#include <zephyr/device.h>
#include <zephyr/devicetree.h>
#include <zephyr/drivers/gpio.h>
#include <zephyr/drivers/spi.h>
#include <zephyr/kernel.h>
#include <zephyr/logging/log.h>

#include <ardep/drivers/hv_shield.h>

LOG_MODULE_REGISTER(hv_shield, CONFIG_HV_SHIELD_LOG_LEVEL);

struct hv_shield_config_t {
  struct spi_dt_spec spi_spec;
  struct gpio_dt_spec oe_gpio_spec;
};

struct __packed hv_shield_registers_t {
  uint32_t gpio_output : 32;  // 1 for output, 0 for input
  enum hv_shield_dac_gains_t dac0 : 4;
  enum hv_shield_dac_gains_t dac1 : 4;
};

BUILD_ASSERT(sizeof(struct hv_shield_registers_t) == 5,
             "Invalid registers size.");

struct hv_shield_data_t {
  struct hv_shield_registers_t registers;
};

/**
 * @brief Internal: writes registers to the shield through spi
 *
 * @param dev hv_shield device
 * @retval 0 on success
 * @retval other from spi_write_dt on error
 */
static int _hv_shield_update(const struct device* dev) {
  const struct hv_shield_config_t* config = dev->config;
  struct hv_shield_data_t* data = dev->data;

  LOG_HEXDUMP_DBG(&data->registers, sizeof(data->registers),
                  "Writing register data");

  uint8_t* raw_buffer = (uint8_t*)&data->registers;
  // bits have to be flipped to match shift registers
  uint8_t rotated_buffer[sizeof(data->registers)];

  // copy inverted bytes (bits are inverted through SPI output order(MSB))
  for (int i = 0; i < sizeof(rotated_buffer); i++) {
    rotated_buffer[i] = raw_buffer[sizeof(rotated_buffer) - i - 1];
  }

  struct spi_buf buffer[] = {
    {.buf = rotated_buffer, .len = sizeof(rotated_buffer)},
  };

  struct spi_buf_set buffer_set = {
    .buffers = buffer,
    .count = ARRAY_SIZE(buffer),
  };

  int err = spi_write_dt(&config->spi_spec, &buffer_set);
  if (err) {
    LOG_ERR("Error writing to spi (%d)", err);
    return err;
  }

  return 0;
}

static int hv_shield_init(const struct device* dev) {
  const struct hv_shield_config_t* config = dev->config;
  struct hv_shield_data_t* data = dev->data;

  int err = gpio_pin_configure_dt(&config->oe_gpio_spec, GPIO_OUTPUT_INACTIVE);
  if (err) {
    LOG_ERR("Error setting up Output enable pin (%d)", err);
    return err;
  }

  // set everything to known state
  memset(&data->registers, 0, sizeof(data->registers));

  err = _hv_shield_update(dev);
  if (err) {
    LOG_ERR("Error writing registers (%d)", err);
    return err;
  }

  err = gpio_pin_set_dt(&config->oe_gpio_spec, 1);
  if (err) {
    LOG_ERR("Error setting enabling output (%d)", err);
  }

  return err;
}

static int hvs_set_dac_gain(const struct device* dev,
                            uint8_t dac,
                            enum hv_shield_dac_gains_t gain) {
  if (dac > 1) return -EINVAL;

  struct hv_shield_data_t* data = dev->data;
  switch (dac) {
    case 0:
      data->registers.dac0 = gain;
      break;
    case 1:
      data->registers.dac1 = gain;
      break;
    default:
      return -EINVAL;
  }

  return _hv_shield_update(dev);
}

static int hvs_set_gpio_output_enable(const struct device* dev,
                                      uint8_t index,
                                      bool enable) {
  if (index > 31) return -EINVAL;

  struct hv_shield_data_t* data = dev->data;

  // index has to be remapped a bit (first 4 bits correspond to 4-7 and next to
  // 0-3 and that for each byte)
  if (index % 8 < 4) {
    index += 4;
  } else {
    index -= 4;
  }

  if (enable) {
    data->registers.gpio_output |= 1 << index;
  } else {
    data->registers.gpio_output &= ~(1 << index);
  }

  return _hv_shield_update(dev);
}

struct hv_shield_api_t api = {
  .set_dac_gain = hvs_set_dac_gain,
  .set_gpio_output_enable = hvs_set_gpio_output_enable,
};

#define HV_SHIELD_EACH(n)                                                    \
  static const struct hv_shield_config_t hv_shield_config_##n = {            \
    .spi_spec = SPI_DT_SPEC_INST_GET(n, SPI_TRANSFER_MSB | SPI_WORD_SET(8)), \
    .oe_gpio_spec = GPIO_DT_SPEC_INST_GET(n, oe_gpios),                      \
  };                                                                         \
  struct hv_shield_data_t hv_shield_data_##n = {};                           \
  DEVICE_DT_INST_DEFINE(n, hv_shield_init, NULL, &hv_shield_data_##n,        \
                        &hv_shield_config_##n, POST_KERNEL,                  \
                        CONFIG_HV_SHIELD_INIT_PRIORITY, &api);

DT_INST_FOREACH_STATUS_OKAY(HV_SHIELD_EACH);

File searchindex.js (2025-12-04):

Search.setIndex({"docnames": ["README", "boards/mercedes/ardep/doc/can_and_lin/index", "boards/mercedes/ardep/doc/changelog/index", "boards/mercedes/ardep/doc/gearshift/index", "boards/mercedes/ardep/doc/gpio/index", "boards/mercedes/ardep/doc/heartbeat_led/index", "boards/mercedes/ardep/doc/index", "boards/mercedes/ardep/doc/on_board_debugger/index", "boards/mercedes/ardep/doc/power_scheme/index", "boards/shields/hv_shield/doc/analog_io/index", "boards/shields/hv_shield/doc/changelog/index", "boards/shields/hv_shield/doc/high_voltage_digital_io/index", "boards/shields/hv_shield/doc/index", "boards/shields/hv_shield/doc/io_config_register/index", "boards/shields/hv_shield/doc/voltage_supply/index", "boards/shields/power_io_shield/doc/index", "boards/shields/power_io_shield/doc/power_supply/index", "bootloader/index", "console/index", "debugging/index", "error_handling/index", "firmware_loader/index", "getting_started/index", "index", "introduction/index", "lib/can_log/README", "lib/index", "lib/iso14229/README", "lib/uds/README", "samples/adc/README", "samples/can/README", "samples/can_usb_bridge/README", "samples/config_jumpers/README", "samples/dac/README", "samples/digital_input_interrupt/README", "samples/gpio_expander/README", "samples/hardware_test/README", "samples/hardware_tester/README", "samples/hv_shield/README", "samples/index", "samples/iso14229/README", "samples/led/README", "samples/lin/commander/README", "samples/lin/commander_scheduler/README", "samples/lin/lin", "samples/lin/responder/README", "samples/lin2can/commander/README", "samples/lin2can/gateway/README", "samples/lin2can/isotp/README", "samples/lin2can/lin2can", "samples/lin2can/responder/README", "samples/lin2can/uds/README", "samples/power_io_shield/end_of_line_tester/README", "samples/power_io_shield/index", "samples/power_io_shield/interrupts/README", "samples/power_io_shield/multiple/README", "samples/power_io_shield/toggle_outputs/README", "samples/uart/README", "samples/uds/README", "samples/uds_bus_sample/README", "samples/uds_legacy/README", "scripts/ardep"], "filenames": ["README.rst", "boards/mercedes/ardep/doc/can_and_lin/index.rst", "boards/mercedes/ardep/doc/changelog/index.rst", "boards/mercedes/ardep/doc/gearshift/index.rst", "boards/mercedes/ardep/doc/gpio/index.rst", "boards/mercedes/ardep/doc/heartbeat_led/index.rst", "boards/mercedes/ardep/doc/index.rst", "boards/mercedes/ardep/doc/on_board_debugger/index.rst", "boards/mercedes/ardep/doc/power_scheme/index.rst", "boards/shields/hv_shield/doc/analog_io/index.rst", "boards/shields/hv_shield/doc/changelog/index.rst", "boards/shields/hv_shield/doc/high_voltage_digital_io/index.rst", "boards/shields/hv_shield/doc/index.rst", "boards/shields/hv_shield/doc/io_config_register/index.rst", "boards/shields/hv_shield/doc/voltage_supply/index.rst", "boards/shields/power_io_shield/doc/index.rst", "boards/shields/power_io_shield/doc/power_supply/index.rst", "bootloader/index.rst", "console/index.rst", "debugging/index.rst", "error_handling/index.rst", "firmware_loader/index.rst", "getting_started/index.rst", "index.rst", "introduction/index.rst", "lib/can_log/README.rst", "lib/index.rst", "lib/iso14229/README.rst", "lib/uds/README.rst", "samples/adc/README.rst", "samples/can/README.rst", "samples/can_usb_bridge/README.rst", "samples/config_jumpers/README.rst", "samples/dac/README.rst", "samples/digital_input_interrupt/README.rst", "samples/gpio_expander/README.rst", "samples/hardware_test/README.rst", "samples/hardware_tester/README.rst", "samples/hv_shield/README.rst", "samples/index.rst", "samples/iso14229/README.rst", "samples/led/README.rst", "samples/lin/commander/README.rst", "samples/lin/commander_scheduler/README.rst", "samples/lin/lin.rst", "samples/lin/responder/README.rst", "samples/lin2can/commander/README.rst", "samples/lin2can/gateway/README.rst", "samples/lin2can/isotp/README.rst", "samples/lin2can/lin2can.rst", "samples/lin2can/responder/README.rst", "samples/lin2can/uds/README.rst", "samples/power_io_shield/end_of_line_tester/README.rst", "samples/power_io_shield/index.rst", "samples/power_io_shield/interrupts/README.rst", "samples/power_io_shield/multiple/README.rst", "samples/power_io_shield/toggle_outputs/README.rst", "samples/uart/README.rst", "samples/uds/README.rst", "samples/uds_bus_sample/README.rst", "samples/uds_legacy/README.rst", "scripts/ardep.rst"], "titles": ["Documentation", "CAN and LIN", "Changelog", "Gearshift", "GPIO", "Heartbeat LED", "ARDEP Board", "On-Board Debugger (OBD)", "Power Scheme", "Analog I/O", "Changelog", "High Voltage Digital I/O", "ARDEP HV Shield", "I/O Config Register", "Voltage Supply", "ARDEP Power IO Shield", "Power IO Shield Power supply", "Bootloader", "Console Output", "Debugging", "Error Handling", "UDS Firmware Loader", "Getting Started", "Welcome to the ARDEP documentation!", "Introduction", "CAN Log Library", "Libraries", "ISO14229 Library", "UDS Library", "ADC Sample", "CAN sample", "CAN USB Bridge sample", "Config Jumpers", "DAC sample", "Digital Input Interrupt Sample", "GPIO Expander", "Hardware Test Sample", "Hardware Tester Sample", "HV Shield", "Samples and Demos", "ISO14229 Sample", "LED Sample", "Lin Commander Sample", "Lin Commander Scheduler Sample", "Lin Samples", "Lin Responder Sample", "Lin2Can Commander Sample", "Lin2Can Gateway Sample", "Lin2Can IsoTP Sample", "Lin2Can Samples", "Lin2Can Responder Sample", "UDS Over LIN sample", "End of line tester firmware", "Power IO Shield Samples", "Interrupts Sample", "Multiple shields sample", "Toggle Outputs Sample", "UART Sample", "UDS Sample", "UDS Bus Sample", "UDS Sample (Legacy)", "ARDEP Command"], "terms": {"The": [0, 1, 3, 4, 5, 7, 8, 9, 11, 13, 14, 16, 17, 18, 19, 20, 21, 22, 24, 25, 27, 28, 29, 30, 31, 32, 33, 34, 35, 36, 38, 42, 45, 47, 48, 52, 55, 56, 57, 59, 60, 61], "main": [0, 4, 7, 14, 17, 27, 28], "i": [0, 1, 2, 3, 5, 7, 8, 12, 14, 16, 17, 18, 19, 20, 21, 22, 23, 24, 25, 28, 31, 34, 35, 36, 42, 45, 46, 47, 50, 51, 52, 54, 58, 59, 60], "sphinx": 0, "code": [0, 22, 27, 28], "ar": [0, 1, 4, 6, 7, 8, 9, 11, 12, 13, 14, 15, 17, 20, 22, 25, 28, 29, 30, 31, 32, 33, 34, 35, 47, 55, 56, 57, 58, 59], "gener": [0, 4, 8, 9, 11, 14, 20, 27, 28, 31], "us": [0, 1, 3, 4, 5, 7, 8, 9, 11, 13, 14, 16, 17, 18, 20, 22, 23, 24, 25, 28, 29, 30, 31, 32, 33, 34, 36, 37, 38, 40, 41, 42, 43, 45, 46, 47, 48, 50, 51, 52, 54, 55, 56, 57, 58, 59, 60], "doxygen": 0, "we": [0, 22, 31, 51], "try": [0, 22], "keep": [0, 7, 20], "close": [0, 22], "possibl": [0, 3, 8, 9, 11, 20, 28], "so": [0, 11, 28, 58], "": [0, 4, 7, 8, 11, 13, 14, 16, 20, 22, 24, 28, 29, 45, 51, 56, 58], "easier": [0, 22], "up": [0, 1, 4, 17, 20, 21, 23, 31, 35, 51, 55, 56, 58, 60], "date": 0, "board": [0, 12, 15, 17, 18, 19, 20, 22, 23, 24, 29, 30, 31, 32, 33, 34, 35, 36, 37, 41, 42, 43, 45, 46, 47, 48, 50, 51, 52, 57, 59, 61], "specif": [0, 17, 19, 24, 27, 28], "arm": [0, 17, 19, 20, 22], "ardep": [0, 1, 7, 10, 16, 17, 18, 20, 21, 22, 24, 25, 28, 29, 30, 31, 32,
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

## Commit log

2026-01-21 chore: upgrade zephyr to v4.3.0 (#35)
    * upgrade zephyr to v4.3.0
    * use USB device stack next
    * enable USB on all ardeps
    * fix ardep-uds runner
    * update log level of uds flash writes to be less verbose
    [hv_shield.c]
2026-08-10 OpenSCAD: add OpenSCAD enclosure source and hardware README note (#53)
    * chore: add parametric OpenSCAD enclosure model ([#54](https://github.com/mercedes-benz/ardep/issues/54))
    * chore: add stl file for easy integration ([#40](https://github.com/mercedes-benz/ardep/pull/40))
    * chore: structure the files into a seperate folder ([#40](https://github.com/mercedes-benz/ardep/pull/40))
    ---------
    [ardep_enclosure.scad, ardep_enclosure.stl]
